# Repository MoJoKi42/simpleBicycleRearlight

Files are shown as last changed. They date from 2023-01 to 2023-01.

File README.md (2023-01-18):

# simpleBicycleRearlight

It's was a quick project to get finally a working rear light for my bicycle. It uses 10x VLMK31R1S2 LEDs (red LEDs from VISHAY) driven with ~13mA constant current. The TS2509 Buck-Converter regulates the output voltage to get the constant current (see circuit diagram!).
PCB and Circuit was made with KiCad.

It works with a standard 6V bicyle dynamo. At my setup it's starts with flashing at slow cycle rotation and goes over to a constant brightness at higher rotations. The minimum needed voltage is about 3.5-4V (RMS).

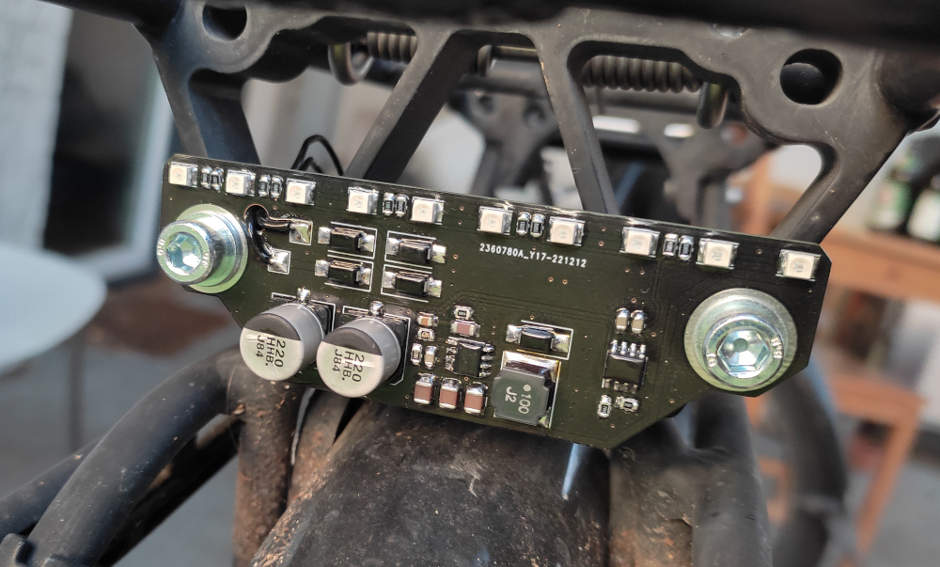
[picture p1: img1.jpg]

The final assembly on my bicycle

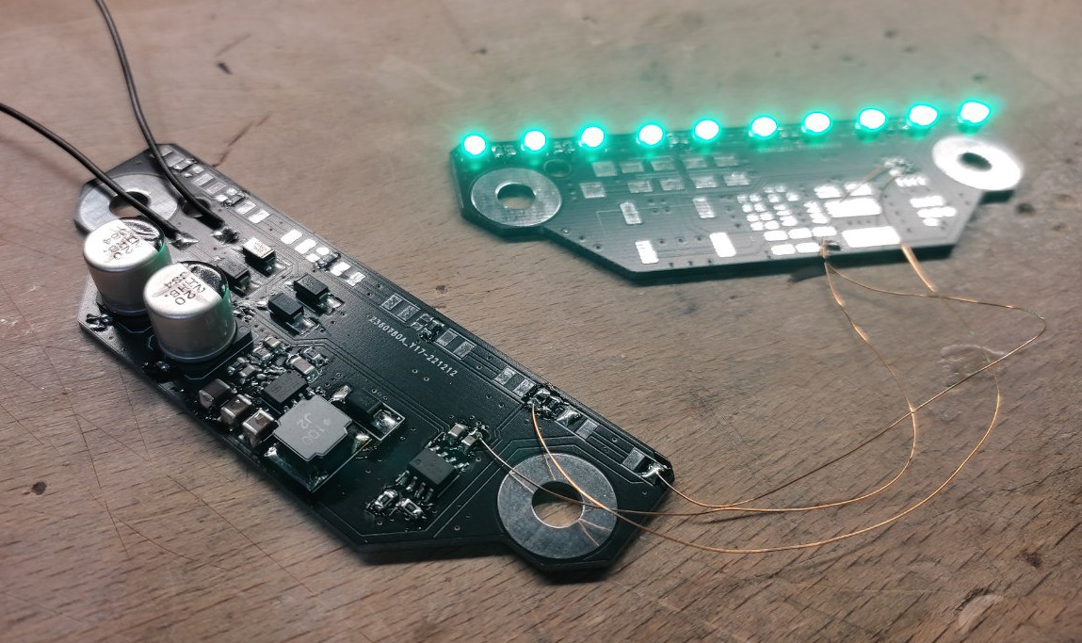
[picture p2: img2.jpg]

Test with some green LEDs

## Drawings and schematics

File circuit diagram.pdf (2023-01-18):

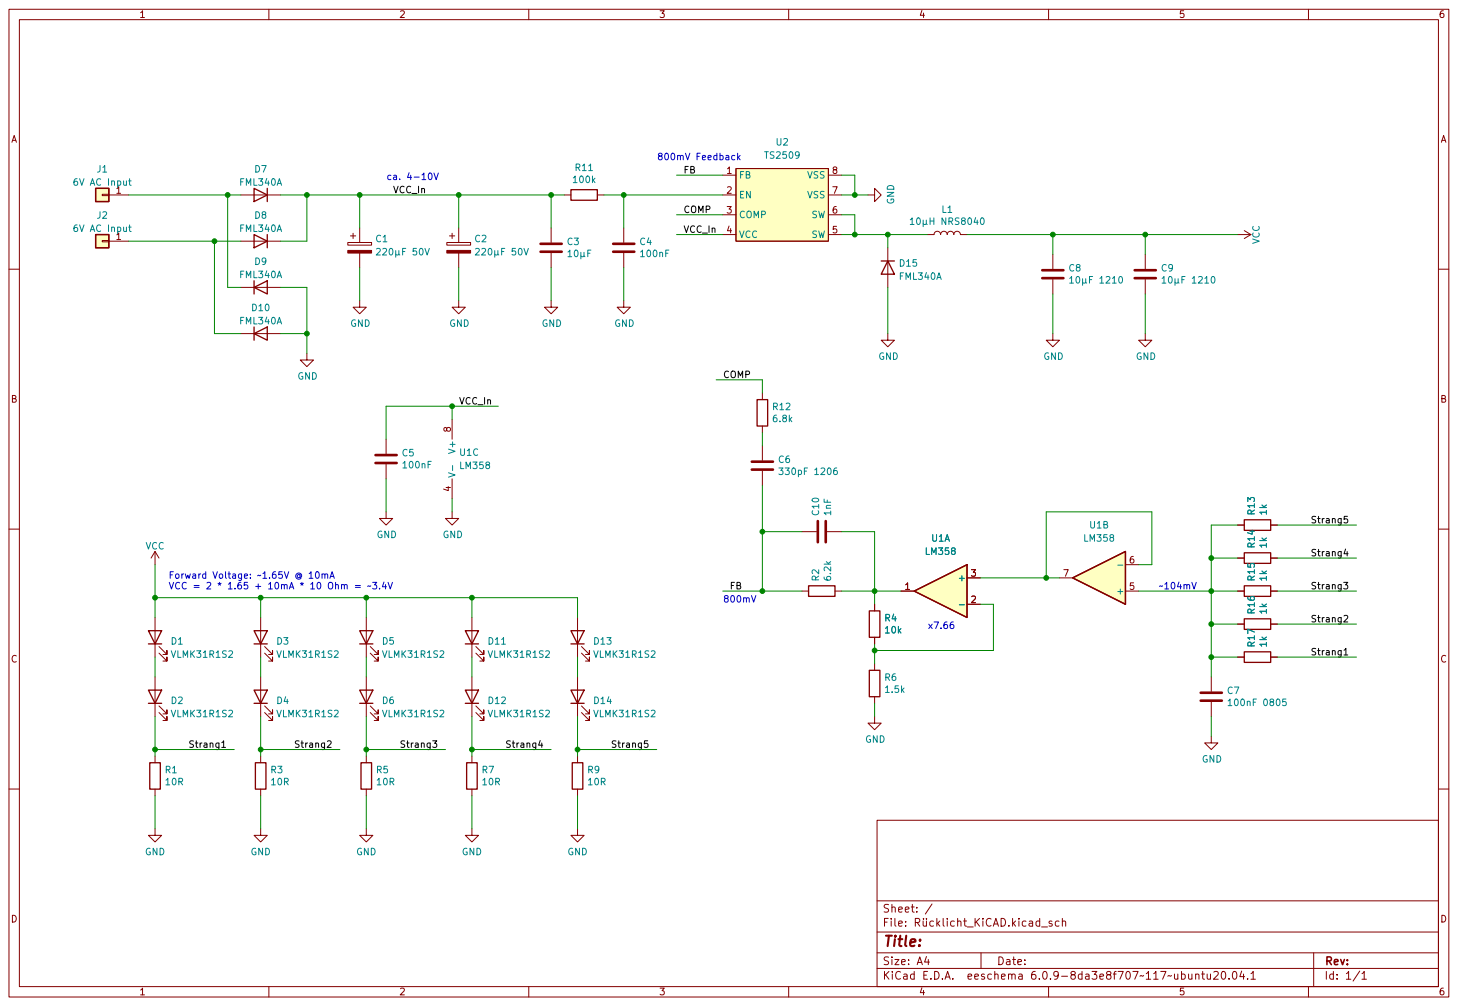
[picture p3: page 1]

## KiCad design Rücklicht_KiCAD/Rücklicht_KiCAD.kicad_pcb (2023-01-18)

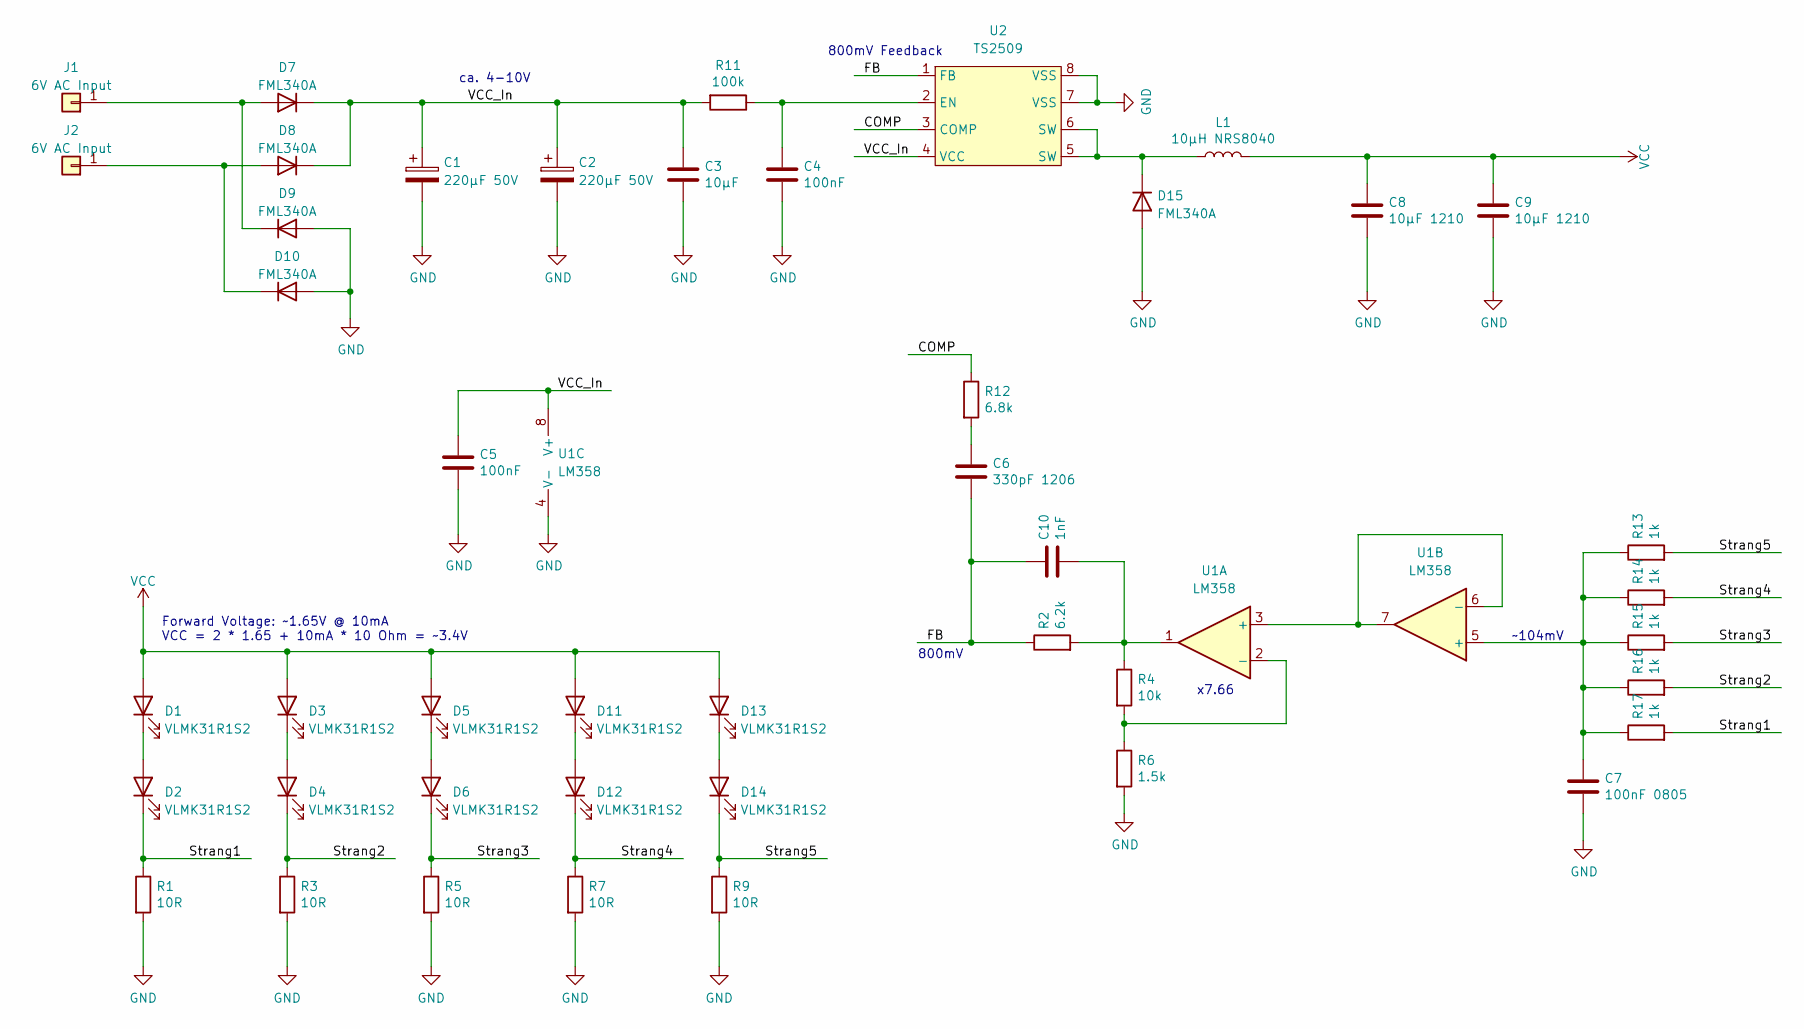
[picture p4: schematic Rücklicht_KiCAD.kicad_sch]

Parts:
C1, C2: 220µF 50V; C_Elec_10x10.2
C3: 10µF; C_1210_3225Metric_Pad1.33x2.70mm_HandSolder
C4, C5: 100nF; C_0805_2012Metric_Pad1.18x1.45mm_HandSolder
C6: 330pF 1206; C_1206_3216Metric_Pad1.33x1.80mm_HandSolder
C7: 100nF 0805; C_0805_2012Metric_Pad1.18x1.45mm_HandSolder
C8, C9: 10µF 1210; C_1210_3225Metric_Pad1.33x2.70mm_HandSolder
C10: 1nF; C_0805_2012Metric_Pad1.18x1.45mm_HandSolder
D1, D2, D3, D4, D5, D6, D11, D12, D13, D14: VLMK31R1S2; LED_PLCC-2
D7, D8, D9, D10, D15: FML340A; D_SMB_Handsoldering
J1, J2: 6V AC Input; TestPoint_Pad_3.0x3.0mm
L1: 10µH NRS8040; L_Taiyo-Yuden_NR-80xx_HandSoldering
R1, R3, R5, R7, R9: 10R; R_0805_2012Metric_Pad1.20x1.40mm_HandSolder
R2: 6.2k; R_0805_2012Metric_Pad1.20x1.40mm_HandSolder
R4: 10k; R_0805_2012Metric_Pad1.20x1.40mm_HandSolder
R6: 1.5k; R_0805_2012Metric_Pad1.20x1.40mm_HandSolder
R11: 100k; R_0805_2012Metric_Pad1.20x1.40mm_HandSolder
R12: 6.8k; R_0805_2012Metric_Pad1.20x1.40mm_HandSolder
R13, R14, R15, R16, R17: 1k; R_0805_2012Metric_Pad1.20x1.40mm_HandSolder
U1: LM358; SO-8_3.9x4.9mm_P1.27mm
U2: TS2509; SO-8_3.9x4.9mm_P1.27mm

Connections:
/COMP: R12.1, U2.3 (COMP)
/FB: C6.2, C10.1, R2.1, U2.1 (FB)
/Strang1: D2.1 (K), R1.1, R17.2
/Strang2: D4.1 (K), R3.1, R16.2
/Strang3: D6.1 (K), R5.1, R15.2
/Strang4: D12.1 (K), R7.1, R14.2
/Strang5: D14.1 (K), R9.1, R13.2
/VCC_In: C1.1, C2.1, C3.1, C5.1, D7.1 (K), D8.1 (K), R11.2, U1.8 (V+), U2.4 (VCC)
GND: C1.2, C2.2, C3.2, C4.2, C5.2, C7.2, C8.2, C9.2, D9.2 (A), D10.2 (A), D15.2 (A), R1.2, R3.2, R5.2, R6.2, R7.2, R9.2, U1.4 (V-), U2.7 (VSS), U2.8 (VSS)
unnamed: C4.1, R11.1, U2.2 (EN)
unnamed: C6.1, R12.2
unnamed: C7.1, R13.1, R14.1, R15.1, R16.1, R17.1, U1.5 (+)
unnamed: C10.2, R2.2, R4.1, U1.1
unnamed: D1.1 (K), D2.2 (A)
unnamed: D3.1 (K), D4.2 (A)
unnamed: D5.1 (K), D6.2 (A)
unnamed: D7.2 (A), D9.1 (K), J1.1
unnamed: D8.2 (A), D10.1 (K), J2.1
unnamed: D11.1 (K), D12.2 (A)
unnamed: D13.1 (K), D14.2 (A)
unnamed: D15.1 (K), L1.1, U2.5 (SW), U2.6 (SW)
unnamed: R4.2, R6.1, U1.2 (-)
unnamed: U1.3 (+), U1.6 (-), U1.7
VCC: C8.1, C9.1, D1.2 (A), D3.2 (A), D5.2 (A), D11.2 (A), D13.2 (A), L1.2

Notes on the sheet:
Forward Voltage: ~1.65V @ 10mA VCC = 2 * 1.65 + 10mA * 10 Ohm = ~3.4V
ca. 4-10V
800mV Feedback
800mV
x7.66
~104mV

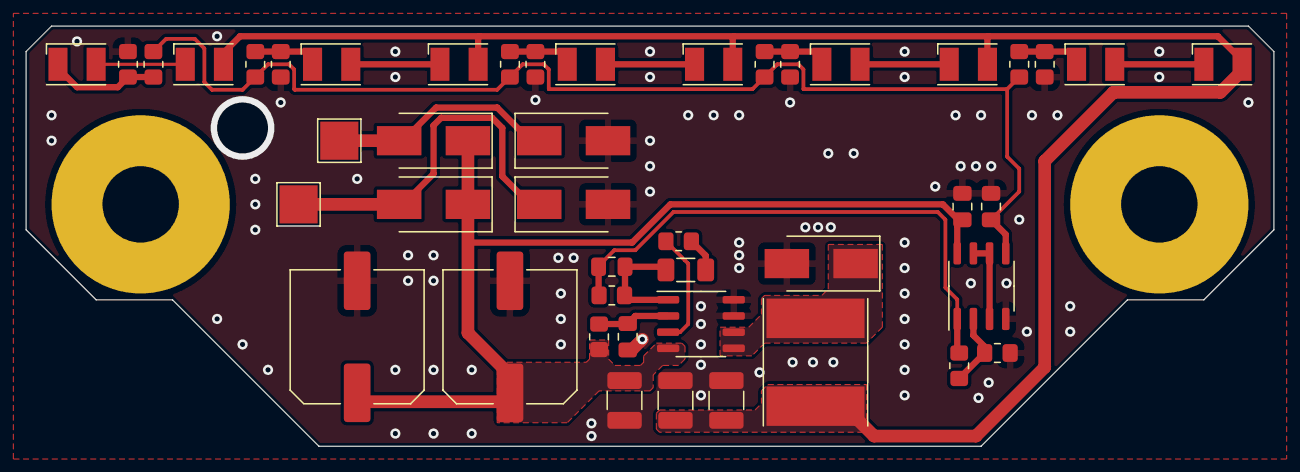
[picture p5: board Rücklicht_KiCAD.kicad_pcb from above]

Board: 2 copper layers, 98.0 x 33.0 mm, 45 parts (0 on the bottom side), 24 nets.
